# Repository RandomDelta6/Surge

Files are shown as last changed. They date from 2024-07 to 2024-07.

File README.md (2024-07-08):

# Introduction

This is a basic Passive Surge Protector PCB. It features robust large traces for high current carrying capacity and ensuring safety by preventing heating along unexpected regions. This board features an extremely small form factor of 61.6mm x 36.3mm so that it can be easily incorporated in any housing. It also features 3 M2 mounting points for securing the board to the housing. It is designed as a single sided pcb to reduce costs. Provides protection against Voltage Spikes, Short Circuit and Over Current.

Continuous Duty Electrical Rating: 250V/15A/50Hz/3750W   
Maximum Energy Dissipation: 396J    
Maximum Spike Current: 12,000 A   
Response Time: Less than 1 nanosecond
Maximum spike voltage: 6kV

Features Include :      
Thermal Resettable Fuse    
Low Cost   
Small Footprint   

# Schematic

 

# PCB

        

PCB Back View



PCB Front View

# Product Design Considerations

Proceed to place all components on the back of the board. Use 10AWG Wires for Input Cabling. Use 0.75 - 1.00 cm brass / copper strips as bus bars for the outlets. rails used for Live and Neutral supply in the Surge Protected Power Strip are expected to be soldered directly to the PCB. The brass strip should be slid in from the back side into the appropriate slit marked for it, folded down on the front side and then soldered onto the large flat pad for it. A short 10AWG wire should be soldered onto the Ground rail to the Ground Output on the PCB. Recommended for 6/8 Outlet Surge Protector Strips. Recommend Body to be made out of Thick ABS. 

The discrete Neon lamp indicates protection status, incase it is not glowing even when neon lamp in TCB is glowing, it indicates the safety circuit is blown and product needs to be replaced, as the lamp is parallel to ouput, when the lamp is not glowing, the devices connected to the strip will no longer be connected to power as well, this is in contrast to general power strips which may continue to supply power to connected devices even after safety circuit is compromised, relying on the user to notice the protection indicator is no longer lit, leaving devices vulnerable.

Thermal Fuses have a slightly higher rating of 20A as opposed to 15A of TCB, TCB has a faster action time and hence will be "resettable" after a brief period of rest when triggered. The thermal fuses act as additional protection incase of failure of TCB to cutoff power even when Current threshold is crossed. Additionally they are sandwiched between the MOVs so that the heat dissipated by MOVs incase of continuous or large Voltage Spike can cause the fuses to reach their activation temperature and blow to cut power to devices.

Dip soldering is recommended for the pcb assembly. All components should be inserted in from the back side , have excess leads trimmed and rail bars folded and then have the front side be dipped in solder bath to ensure uniform and sufficient solder coverage for efficient electrical connection.

Plastic Prongs or Screw Posts maybe provided on the frame for mounting the PCB. 3 M2 holes are provided on PCB for attaching via screws or plastic push pins. Flat Plastic Protrusions maybe used as guides for PCB placement as well as enhanced isolation, they are expected to slide into the long rectangular cutouts between L out and N out traces and N and E traces. 

# Notes

All items are mounted on the back of the board. A 23AWG wire (0 ohm link) should be run across the back of the board from Epass1 to Epass2. Solder mask is not used on either side of the board. It is not used on the front to allow for deposited solder to increase current carrying capacity. It is not used on the back since it is not required. All copper traces are on the front side of the board only as a cost saving measure. NPTH maybe used to reduce cost further. 

The Fuse and MOV Array maybe encapsulated in a piece of heatshrink tube of sufficient size.  The Brass rails used for Live and Neutral supply in the Surge Protected Power Strip are expected to be soldered directly to the PCB. The brass strip should be slid in from the back side into the appropriate slit marked for it, folded down on the front side and then soldered onto the large flat pad for it. 

Couldn't find a proper model for Thermal Circuit Breaker, so it is missing in PCB view.

This project was made with Kicad 7.0 . Updated on Kicad 8.0.3   
Generate gerbers as per specifications of the fab of your choice.

# Disclaimer
This board has not been printed and tested physically to verify functionality. I do not assume any liability for the materials, information and opinions provided on, or available through, this project. I disclaim any liability for injury, death or damages resulting from the use thereof. Modify or work on it at your own risk.

# Licensing
All PCB design files and hardware are released under the [Creative Commons Attribution Share Alike 4.0 license](https://choosealicense.com/licenses/cc-by-sa-4.0/). 

Commercial Usage strictly disallowed.

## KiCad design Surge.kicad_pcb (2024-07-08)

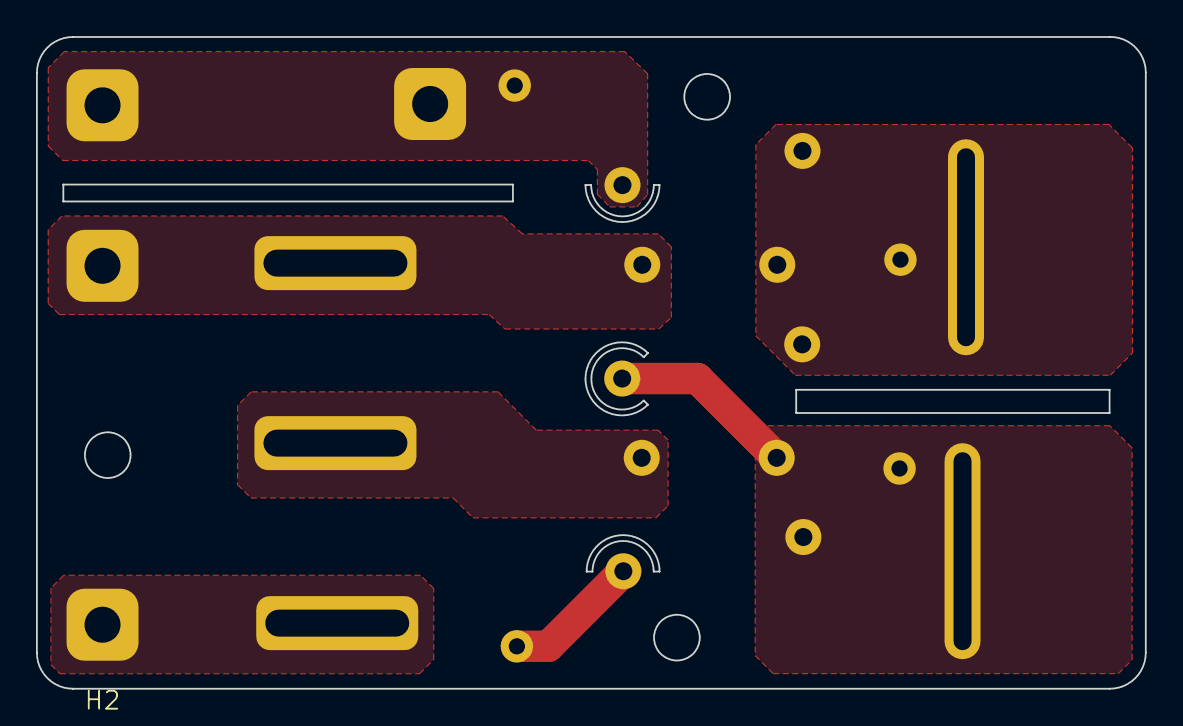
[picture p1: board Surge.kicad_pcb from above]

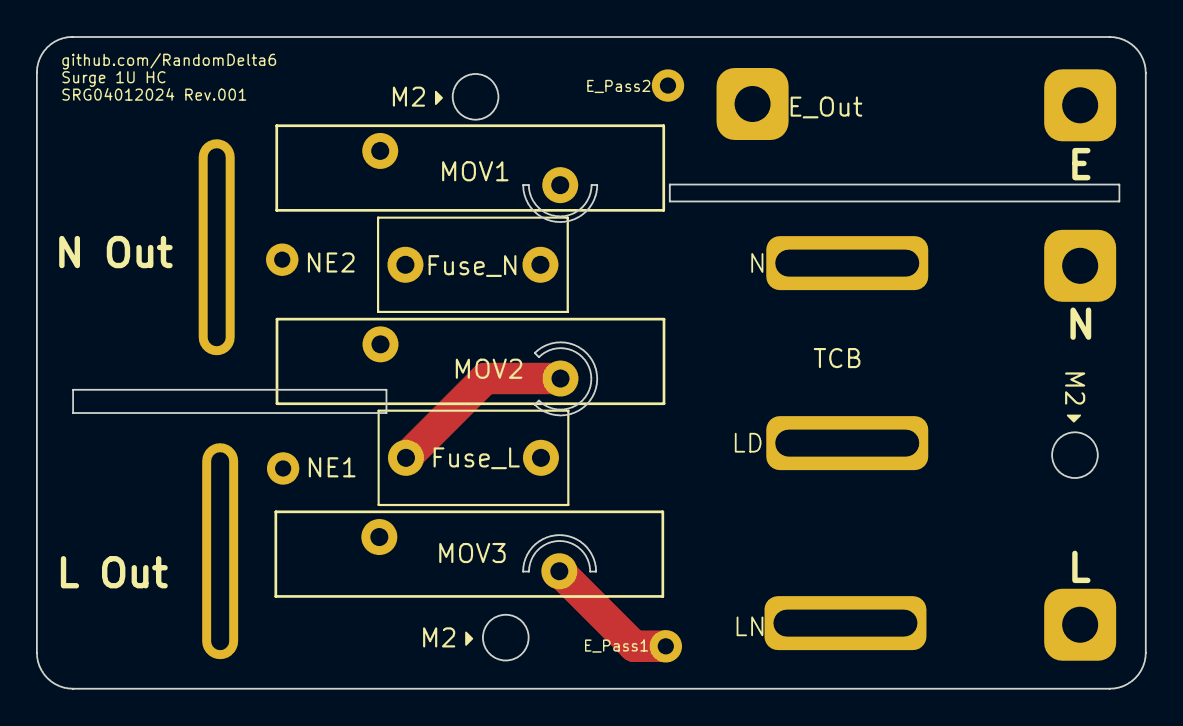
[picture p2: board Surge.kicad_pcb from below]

Board: 2 copper layers, 61.6 x 36.2 mm, 16 parts (6 on the bottom side), 7 nets.

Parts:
F1, F2: TCO 115C 20A 250V; C_Rect_L10.3mm_W5.0mm_P7.50mm_MKS4
H1: N_in; I_Hole
H2: L_in; I_Hole
H3: E_in; I_Hole
H4: N_out; L_Hole
H5: L_out; L_Hole
H6: E_out; I_Hole
J1, J2: NEmount
NE1: NE_N; NEmount
NE2: NE_L; NEmount
RV1, RV2, RV3: 471K; RV_Disc_D21.5mm_W4.7mm_P10mm
SW1: C1005B 15A TCB; Switch

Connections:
Earth: H3.1, H6.1, J2.1, RV1.2
unnamed: F1.1, H4.1, NE1.1, RV1.1, RV2.1
unnamed: F2.1, H5.1, NE2.1, RV2.2, RV3.1
unnamed: J1.1, RV3.2
unnamed: H2.1, SW1.3 (Line)
unnamed: F2.2, SW1.2 (Load)
unnamed: F1.2, H1.1, SW1.1 (N)

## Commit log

2023-12-21 update values
    [Surge.kicad_sch]
2023-12-22 Updated Footprints
2023-12-23 update footprints
    [Surge.kicad_pcb, Surge.kicad_sch]
2024-01-03 Updated board layout
    [Surge.kicad_pcb, Surge.kicad_sch]
2024-01-14 Refined Layout
    [Surge.kicad_pcb, Surge.kicad_sch, rocker switch 1.IGS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]
2024-01-14 update layout
    [Surge.kicad_pcb, Surge.kicad_sch]
2024-01-19 Update Schematics
    [Surge.kicad_pcb, Surge.kicad_sch, rocker switch 1.IGS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]
2024-07-08 Update BOM and ReadMe
    [Component Glossary.csv, Component Glossary.xlsx, Surge.kicad_pcb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]
